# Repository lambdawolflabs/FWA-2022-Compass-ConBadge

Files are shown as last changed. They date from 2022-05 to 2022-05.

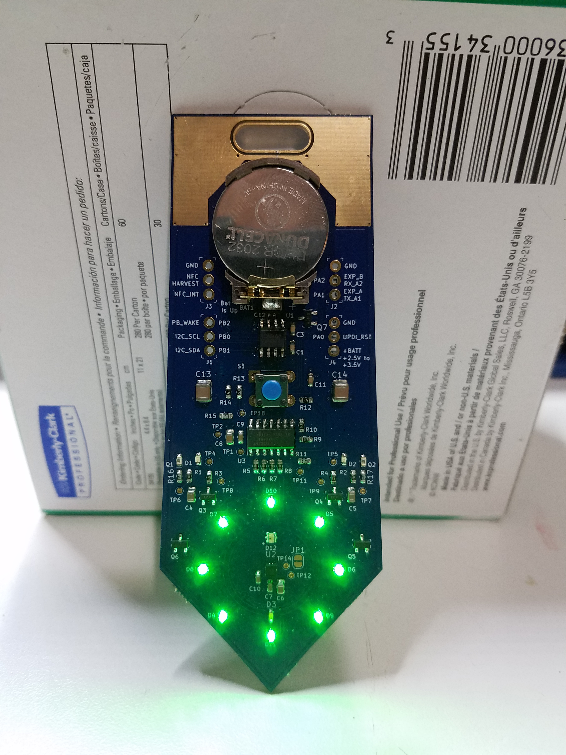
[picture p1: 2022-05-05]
misc/20220504_211331.jpg

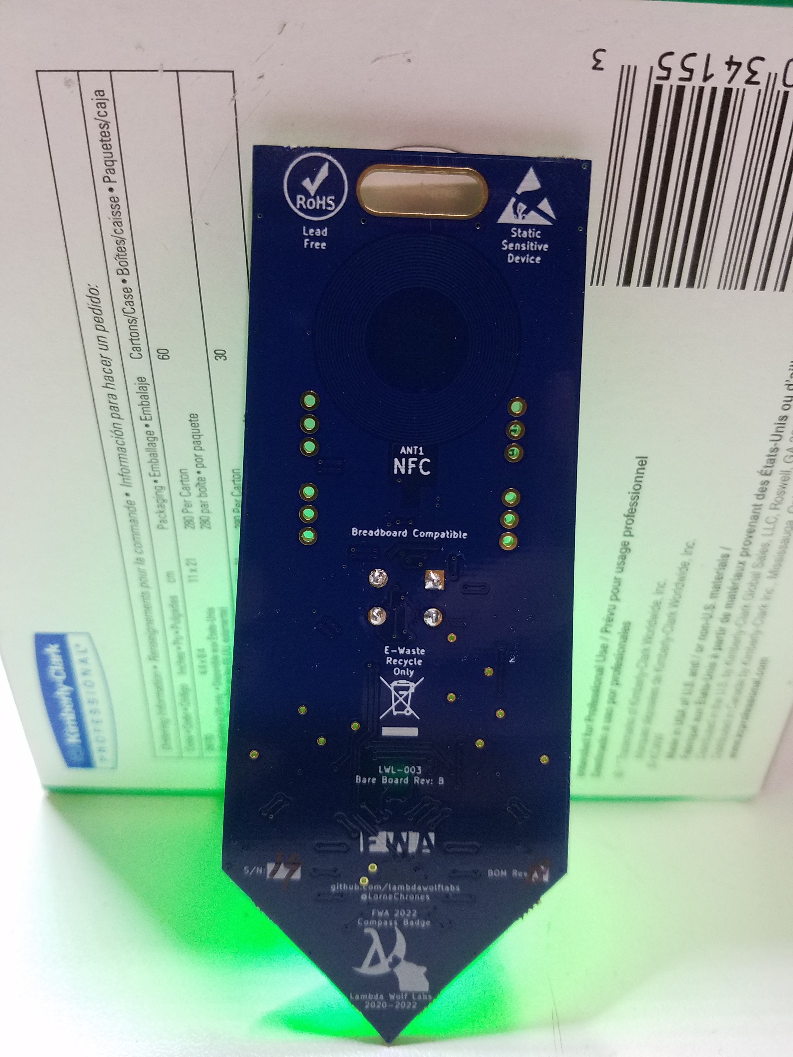
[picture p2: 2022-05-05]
misc/20220504_211339.jpg

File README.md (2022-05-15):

# FWA-2022-Compass-ConBadge
FWA 2022 Compass ConBadge from the Intro To DIY Electronics &amp; Electrical Engineering Panel!

Slides: https://docs.google.com/presentation/d/1c4_kWb6G9Z7fMHBQ-3chpQz8QXO9tOMy/edit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

Recorded Panel: https://www.youtube.com/watch?v=K9LNleyEv4E 

Purpose: Semi-basic, semi-intelligent, semi-interactive conbadge with LED compass function, two BJT transistor multivibrator flasher (can be disabled by MCU), MCU runs the show and built in NFC tag.

Specs:
	
	>Operating/Storage Ambient Temperature Range: 0°C to 40°C.
	
	>Operating/Storage Ambient Humidity Range: 10% to 95% RH.
	
	>Atlantis TLE Theme. Atlantean Crystal Necklace in color (Blue soldermask) and overall shape. 
		
		>PCB is in a truncated cone/prism pill shape with a multi-angled (rounded) arrow end at the large side of the truncation. ~2-3" long by ~1.5" wide.
			
			>Large arrow rounded end is for the compass sensor and compass LEDs.
			
			>Shaft holds most of the electronics (MCU, NFC transiever, pushbutton, etc).
			
			>Smaller flat end holds the battery mount, NFC antenna and lanyard hole.
			
			>NFC antenna is circular with a similar (copyright legal) look to the Eye of Atlantis.

Goals & Requirements:
	
	-EU ROHS3 COMPLIANT
	
	-NO EXPLICIT ESD PROTECTION.
	
	-Has a hole for a keychain or lanyard hook.
	
	-Powers off a single CR2032.
		
		-Lasts atleast 12 hours of continuous compass function (MCU/Compass active + compass LED) and nominal frequency multivibrator flasher (one LED lit at a time): <7mA
		
		-Lasts atleast 24 hours of continuous nominal frequency multivibrator flasher alone (one LEDs lit at any given time)
		
		-Lasts atleast 8 hours of continuous EVERYTHING ON/MAXED OUT operation.
	
	-Simple 2 BJT transistor astable multivibrator circuit.
	
	-Simple integrated NFC rewriteable tag that can be programmed via smartphone.
		
		-Antenna is fully made in PCB FR-4.
		
		-NFC tag harvest output can be used to power downstream circuits without coin cell (optional).
	
	-Compass function:
		
		-Three axis magnetoer/compass sensor (+ accel and/or gyro? optional) for determining which way is north.
		
		-MCU reads this off.
		
		-Charlieplexed LED array in 8 point circle. Only a single LED lights up to point which way is north.
		
		-Reprogrammable MCU (Only wakes up upon button hold to update compass).
	
	-Optional White LED for general illumination.
	
	-Optional RGB LED for customization (Vanilla FW reads the RGB value stored in the NFC chip).
	
	-Additional pins from the MCU broken out for UPDI reprogramming (FTDI pinout), two additional GPIOs (+ VDD & GND).
	
	-OSHPark Prototype PCB Process Compatible

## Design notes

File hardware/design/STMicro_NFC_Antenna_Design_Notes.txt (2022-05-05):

ST25DV04 NFC Antenna Design (See AN2866)

fNFC_min = 13.553MHz
fNFC_typ = 13.56MHz
fNFC_max = 13.567MHz

Operating field according to ISO (across -40 - 85C):
min: 150 mA/m
max: 5000 mA/m

ST25DV04 SOIC-8 Internal Tuning Capacitance:
min = 26.5pF
typ = 28.5pF
max = 30.5pF

Ideal Antenna Inductance (assuming no other parasitics & typ NFC frequency):
min = 5.984uH
typ = 4.833uH
max = 4.516uH

Ideal Antenna Geometry (assuming no other parasitics & 4.833uH Antenna Inductance):
Circular Spiral Geometry:
Turns: 25
Conductor Spacing: 0.18mm
Conductor Width: 0.18mm
Outer Diameter: 19.5mm
	Inner Diameter: 1.86mm
	Fill Factor: 0.8258um
	Resultant Inductance: 4.825uH 
	Calculated Trace Length: 2383mm
	Calculated Trace Resistance (1oz cu, 35um): 6.43 Ohms

Octagonal Spiral Geometry (opt 1):
Turns: 24
Conductor Spacing: 0.18mm
Conductor Width: 0.18mm
Outer Diameter: 19.5mm
	Inner Diameter: 2.58mm
	Fill Factor: 0.7663um
	Resultant Inductance: 4.830uH
	Calculated Trace Length: 1119mm
	Calculated Trace Resistance (1oz cu, 35um): 3.02 Ohms

Octagonal Spiral Geometry (opt 2):
Turns: 15
Conductor Spacing: 0.18mm
Conductor Width: 0.18mm
Outer Diameter: 21.5mm
	Inner Diameter: 11.06mm
	Fill Factor: 0.3206um
	Resultant Inductance: 4.841uH
	Calculated Trace Length: 864mm
	Calculated Trace Resistance (1oz cu, 35um): 2.33 Ohms

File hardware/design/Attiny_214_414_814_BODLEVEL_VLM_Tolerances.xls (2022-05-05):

BODLEVEL (V) | BODLEVEL HYS (V) | BODLEVEL ABS MAX, No Hys (V) | BODLEVEL ABS MIN, No Hys (V) | High Side Tol, No Hys (%) | Low Side Tol, No Hys (%)
4.2 | 0.08 | 4.5 | 3.9 | 6.897 | 7.407
2.6 | 0.04 | 2.9 | 2.4 | 10.909 | 8.000
1.8 | 0.025 | 2 | 1.7 | 10.526 | 5.714
 |  |  |  |  | Voltage Level Monitor (VLM) Setpoints
BODLEVEL (V) | Calc. High Side Tol (%) | Calc. Low Side Tol (%) | Calc. ABS Max + Calc. Hys (V) | Calc. ABS Min + Calc. Hys (V) | 5% Over ABS Max (V) | 5% O. ABS Min (V) | 15% Over Abs Max (V) | 15% O. Abs Min (V) | 25% Over Abs Max (V) | 25% O. Abs Min (V)
1.8 | 10.526 | 5.714 | 2.025 | 1.675 | 2.126 | 1.759 | 2.329 | 1.926 | 2.531 | 2.094
2.15 | 10.890 | 6.926 | 2.415 | 2.032 | 2.536 | 2.134 | 2.778 | 2.337 | 3.019 | 2.540
2.6 | 10.909 | 8.000 | 2.940 | 2.360 | 3.087 | 2.478 | 3.381 | 2.714 | 3.675 | 2.950
2.95 | 10.576 | 8.459 | 3.310 | 2.748 | 3.475 | 2.885 | 3.806 | 3.160 | 4.137 | 3.435
3.3 | 9.938 | 8.588 | 3.684 | 3.072 | 3.868 | 3.226 | 4.236 | 3.533 | 4.605 | 3.840
3.7 | 8.835 | 8.332 | 4.093 | 3.458 | 4.298 | 3.631 | 4.707 | 3.976 | 5.116 | 4.322
4 | 7.747 | 7.858 | 4.384 | 3.760 | 4.603 | 3.948 | 5.042 | 4.324 | 5.480 | 4.700
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

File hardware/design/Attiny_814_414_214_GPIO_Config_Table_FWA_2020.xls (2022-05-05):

Physical Pin # | Pin Function/Software Pin # | Netname | Peripheral | Direction | Notes
10 | PA0 | UPDI_RST | UPDI / RESET | In | Dedicated programming/reset/debug pin.
11 | PA1 | EXP_A_TXD_A1 | GPIO | In | Expansion GPIO pin (Either ADC AIN1, BREAK, UART TXD or other misc. functions) - Brought out to board edge.
12 | PA2 | EXP_B_RXD_A2 | GPIO | In | Expansion GPIO pin (Either ADC AIN2, EVOUT0, UART RXD or other misc. funcs) - Brought out to board edge.
13 | PA3 | INT_MUX | GPIO/ADC | In | Multiplexed interrupt line from NFC tag & Magnetometer (ADC decoding, digital falling/rising edge detection to check for both Hi-Z or one/both pulled low)
2 | PA4 | LED_CHARLIE_A | GPIO | Out | Charlieplexed output for LED array (A)
3 | PA5 | LED_CHARLIE_B | GPIO | Out | Charlieplexed output for LED array (B)
4 | PA6 | LED_CHARLIE_C | GPIO | Out | Charlieplexed output for LED array (C)
5 | PA7 | LED_CHARLIE_D | GPIO | Out | Charlieplexed output for LED array (D)
9 | PB0 | I2C_SCL | I2C (SCL) | Out | Board I2C Bus - Brought out to board edge.
8 | PB1 | I2C_SDA | I2C (SDA) | Bidirectional | Board I2C Bus - Brought out to board edge.
7 | PB2 | PB_WAKE | GPIO | In | Wakeup Pushbutton/multifunction pushbutton - Brought out to board edge.
6 | PB3 | BLINK_DIS | GPIO | Out | GPIO disable/enable for the two transistor multivibrator oscillator.
 | See the Attiny814 datasheet for the latest revision to the pinout.

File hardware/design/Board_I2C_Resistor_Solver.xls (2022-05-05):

Device Name | Device RefDes | Device I2C/TWI Pin Capacitance (pF)
Attiny414 | U3 | 10
LIS3MDLTR | U2 | 8
ST25DV04K | U1 | 10
I2C Expansion Device From J1 | - | 8
I2C Net Trace Capacitance (0.18mm width, FR4, 1.52mm core thickness, 6.5cm total length), pF: |  |  | 3
I2C Expanson Bus J1 Wire Capacitance (Arbitrary 22AWG hook-up wire + 2pF Breadboard capacitance), pF: |  |  | 2.5
I2C Target Speed (kHz): | 100
I2C Rise Time (uS): | 1
Maximum I2C Pull Up Resistor (kΩ): | 28.4390246

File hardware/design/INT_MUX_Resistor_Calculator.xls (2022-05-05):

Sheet: Only MAG_INT and NFC_INT
MCU or Ext Pullup Typ: | 27 | kΩ
MCU or Ext Pullup Tol: | 1.2 | %
ST25DV04 GPO Open Drain Max: | 0.4 | kΩ |  | Note: Open Drain Drive can vary from 50Ω to typ 200Ω to max 400Ω
LIS3MDL INT Output Impedance Max: | 0.06 | kΩ
NFC_INT PD Res Typ: | 4.7 | kΩ | Parallel Combo: | 2.889344262 | kΩ
NFC_INT PD Res Tol: | 1.2 | % | Total Error: | 3.6851 | %
 |  |  |  |  |  |  | 0.0034155
MAG_INT PD Res Typ: | 7.5 | kΩ
MAG_INT PD Res Tol: | 1.2 | % | MCU ADC Bits: | 10 | Bits
LIS3MDL & ST25DV04 Max Pin Leakage: | 0.2 | uA
 | 3.2 | Vin |  |  |  | 3 | Vin |  |  |  | 2.5 | Vin
Combination | Vmeasure Typ | Vmeasure Max | Vmeasure Min | VIH Min | VIL Max | Vmeasure Typ | Vmeasure Max | Vmeasure Min | VIH Min | VIL Max | Vmeasure Typ | Vmeasure Max | Vmeasure Min | VIH Min | VIL Max
Both Hi-z | 3.200 | 3.200 | 3.189 | 2.240 | 0.960 | 3.000 | 3.000 | 2.989 | 2.100 | 0.900 | 2.500 | 2.500 | 2.489 | 1.750 | 0.750
NFC_INT shorted, MAG_INT Hi-Z | 0.469 | 0.486 | 0.452 | 2.240 | 0.960 | 0.439 | 0.456 | 0.423 | 2.100 | 0.900 | 0.365 | 0.379 | 0.352 | 1.750 | 0.750
NFC_INT Hi-Z, MAG_INT shorted | 0.690 | 0.716 | 0.665 | 2.240 | 0.960 | 0.647 | 0.671 | 0.623 | 2.100 | 0.900 | 0.538 | 0.558 | 0.518 | 1.750 | 0.750
Both shorted | 0.309 | 0.321 | 0.298 | 2.240 | 0.960 | 0.290 | 0.301 | 0.279 | 2.100 | 0.900 | 0.242 | 0.251 | 0.233 | 1.750 | 0.750
Min Delta Between States: | 0.1597102284 |  |  |  |  | 0.1493908391 |  |  |  |  | 0.123592366
Max Percentage Spread: | 0.1180327003 |  |  |  |  | 0.1106624875 |  |  |  |  | 0.09223695557
Max ADC Resolution: | 0.003125 |  |  |  |  | 0.0029296875 |  |  |  |  | 0.00244140625
Max (Delta BW States - Percentage Spread) in ADC Steps: | 13 |  |  |  |  | 13 |  |  |  |  | 12
Values & Tolerances Good? (Also accounts for all ADC drift, error & linearity): | YES |  |  |  |  | YES |  |  |  |  | YES
Max of any shorted condition (V): | 0.716 |  |  |  |  | 0.671 |  |  |  |  | 0.558
Less than max VIL? | YES |  |  |  |  | YES |  |  |  |  | YES
Confirmed MAG_INT is indeed a open-drain ouput according to the ST Micro forums

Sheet: CMOS MAG_INT Alternate
MCU or Ext Pullup Typ: | 27 | kΩ
MCU or Ext Pullup Tol: | 1.2 | %
ST25DV04 GPO Open Drain Max: | 0.4 | kΩ
LIS3MDL INT Output Impedance Max: | 0.06 | kΩ
NFC_INT PD Res Typ: | 4.7 | kΩ
NFC_INT PD Res Tol: | 1.2 | %
MAG_INT Res Typ: | 7.5 | kΩ
MAG_INT Res Tol: | 1.2 | %
LIS3MDL & ST25DV04 Max Pin Leakage: | 0.2 | uA
MCU / EXT Pullup || MAG_INT Resistor: | 5.869565217
MAG_INT HIGH, NFC_INT shorted low v-divider factor (Typ): | 0.445

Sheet: MAG_INT + MAG_DRDY or NFC_INT
Device: | LIS3MDL |  | ST25DV04K-IER
Combination | MAG_INT (7.5kΩ) | MAG_DRDY (through MAG_INT Resist) | NFC_INT (4.7kΩ) | Captured? | Sim Timecode? (sec) | Verified? | Board Verified? | INT_MUX Nominal (V) | ADC LSB @ 3V # | INT_MUX + Variance (V) | INT_MUX - Variance (V) | Max Variance From Nominal (V) | Max Var/2 | Above VIH or Below VIL? | Device Detected | Combination Overlap Detected? | Variance to ADC LSBs*
1 | Hi-Z | Hi-Z | Hi-Z | Yes | 0 to 0.2 | YES | YES | 2.98 | 1016 | 3 | 2.95 | 0.03 | 0.015 | Yes | None | No | 9
5 | LOW | Hi-Z | Hi-Z | Yes | 0.77 to 0.98 | YES | YES | 0.67 | 228 | 0.691 | 0.645 | 0.025 | 0.0125 | Yes | LIS3MDL | No | 7
2 | Hi-Z | Hi-Z | LOW | Yes | 1.55 to 1.7 | YES | YES | 0.465 | 158 | 0.486 | 0.442 | 0.023 | 0.0115 | Yes | ST25DV04K | No | 6
6 | LOW | Hi-Z | LOW | Yes | 1.05 to 1.45 | YES | YES | 0.301 | 102 | 0.315 | 0.287 | 0.014 | 0.007 | Yes | LIS3MDL & ST25DV04K | No | 4
3 | Hi-Z | LOW | Hi-Z | Yes | 0.26 to 0.48 | YES | YES | 0.667 | 227 | 0.691 | 0.645 | 0.024 | 0.012 | Yes | LIS3MDL | No | 7
7 | LOW | LOW | Hi-Z | Yes | 0.51 to 0.73 | YES | YES | 0.661 | 225 | 0.678 | 0.643 | 0.018 | 0.009 | Yes | LIS3MDL | No | 5
4 | Hi-Z | LOW | LOW | Yes | 1.76 to 1.98 | YES | YES | 0.301 | 102 | 0.315 | 0.287 | 0.014 | 0.007 | Yes | LIS3MDL & ST25DV04K | No | 4
8 | LOW | LOW | LOW | Yes | 3.27 to 3.4 | YES | YES | 0.3 | 102 | 0.312 | 0.287 | 0.013 | 0.0065 | Yes | LIS3MDL & ST25DV04K | No | 3
 |  |  |  |  |  |  |  |  |  |  | Note: This is assuming MAG_INT and MAG_DRDY ARE tied together through the same resistor to INT_MUX
 |  |  |  |  |  |  |  |  |  |  | Note: Variance assumes W.C across 50Ω,200Ω,400Ω open drain resistance, 1% tolerant resistors and 0.2% temp variation
 |  |  |  |  |  |  |  |  |  |  | Note: *ATTINY814 ADC LSB with VCC as the VREF, 10-bit resolution. W.C. with 3.4V vin.
 |  |  |  |  |  |  |  |  |  |  | Device Detected | ADC LSB Nominal Average* | ADC LSB W.C. Upper Range* | ADC LSB W.C. Lower Range*
 |  |  |  |  |  |  |  |  |  |  | None | 1016 | 1023 | 1005
 |  |  |  |  |  |  |  |  |  |  | LIS3MDL | 226 | 235 | 219
 |  |  |  |  |  |  |  |  |  |  | ST25DV04K | 158 | 165 | 150
 |  |  |  |  |  |  |  |  |  |  | LIS3MDL & ST25DV04K | 102 | 107 | 97

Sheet: MAG_INT, NFC_INT and MAG_DRDY
Combination | MAG_INT (7.5kΩ) | MAG_DRDY (1kΩ) | NFC_INT (4.7kΩ) | Captured? | Sim Timecode? (sec) | Verified? | INT_MUX Nominal (V) | ADC LSB @ 3V # | INT_MUX + Variance (V) | INT_MUX - Variance (V) | Max Variance From Nominal (V) | Max Var/2 | Above VIH or Below VIL? | Combination Overlap Detected? | Combination Buffer (V) | Buffer # Of ADC LSBs *
1 | Hi-Z | Hi-Z | Hi-Z | Yes | 0 to 0.2 | YES | 2.98 | 1016 | 3 | 2.9 | 0.08 | 0.04 | Yes | No | 2.208 | 664
5 | LOW | Hi-Z | Hi-Z | Yes | 0.77 to 0.98 | YES | 0.682 | 232 | 0.692 | 0.669 | 0.013 | 0.0065 | Yes | No | 0.182 | 54
2 | Hi-Z | Hi-Z | LOW | Yes | 1.55 to 1.7 | YES | 0.482 | 164 | 0.487 | 0.469 | 0.013 | 0.0065 | Yes | No | 0.153 | 46
6 | LOW | Hi-Z | LOW | Yes | 1.05 to 1.45 | YES | 0.311 | 106 | 0.316 | 0.304 | 0.007 | 0.0035 | Yes | No | 0.153 | 46
3 | Hi-Z | LOW | Hi-Z | Yes | 0.26 to 0.48 | YES | 0.15 | 51 | 0.151 | 0.146 | 0.004 | 0.002 | Yes | No | 0.017 | 5
7 | LOW | LOW | Hi-Z | Yes | 0.51 to 0.73 | YES | 0.128 | 43 | 0.129 | 0.124 | 0.004 | 0.002 | Yes | POTENTIAL COLLISION DETECTED | 0.004 | 1
4 | Hi-Z | LOW | LOW | Yes | 1.76 to 1.98 | YES | 0.119 | 40 | 0.12 | 0.115 | 0.004 | 0.002 | Yes | POTENTIAL COLLISION DETECTED | 0.009 | 2
8 | LOW | LOW | LOW | Yes | 3.27 to 3.4 | YES | 0.104 | 35 | 0.106 | 0.101 | 0.003 | 0.0015 | Yes | No | 0.101 | 30
 |  |  |  |  |  |  |  |  |  | Note: This is assuming MAG_INT and MAG_DRDY are NOT tied together through the same resistor to INT_MUX.
 |  |  |  |  |  |  |  |  |  | Note: Variance assumes W.C. open drain resistance, 1% tolerant resistors and 0.2% temp variation
 |  |  |  |  |  |  |  |  |  | Note: ATTINY814 ADC LSB with VCC as the VREF, 10-bit resolution. W.C. with 3.4V vin.

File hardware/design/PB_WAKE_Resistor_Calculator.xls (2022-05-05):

MCU or Ext Pullup Typ: | 35 | kΩ
MCU or Ext Pullup Tol: | 43 | %
Pushbutton PD Resistor Typ (Ideal Pushbutton): | 4.7 | kΩ
Pushbutton PD Resistor Tol (Ideal Pushbutton): | 1.2 | %
PB_WAKE Capacitor Typ: | 100 | nF
PB_WAKE Capacitor Tol: | 20 | %
MCU VIL Max (Factor): | 0.3 | Factor
MCU VIH Min (Factor): | 0.7 | Factor
MCU W/C GPIO Leakage Current: | 0.050 | uA
Pushbutton Pressed, W/C VIL Factor on PB_WAKE: | 0.193 | Factor
Pressed Condition Less Than MCU VIL Max? | YES
Pushbutton Released, W/C VIH Factor on PB_WAKE: | 0.9974975 | Factor
Released Condition Greater Than MCU VIH Min? | YES
Pushbutton Falling RC Time Typ: | 0.00047 | Sec
Pushbutton Falling RC Time Tol (Calculated): | 21.2 | %
Pushbutton Rising RC Time Typ: | 0.0035 | Sec
Pushbutton Rising RC Time Tol (Calculated): | 63.000 | %

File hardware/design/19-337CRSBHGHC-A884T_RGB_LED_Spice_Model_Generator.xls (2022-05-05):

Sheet: Red
Everlight 19-337C/RSBHGHC-A88/4T RGB LED SMT | RED
From datasheet |  | 69.97 | IS: | 1.6137e-10
 |  | 0.53 | N: | 2.979
Datasheet 25°C Ambient
 |  | .model 19-337_RED D(Is=1.6137e-10 N=2.979)
 |  |  | IS: | 1.6137e-10
 |  |  | N: | 2.979
 |  |  | Rs:
Datasheet VD (V) | Datasheet IF (mA) | Calculated IF (mA) |  | % Diff
1.781 | 0.9 | 1.868661637 |  | -69.9732769
1.8 | 2.3 | 2.392720416 |  | -3.95167015
1.829 | 5 | 3.489467683 |  | 35.58603139
1.859 | 7.7 | 5.155573703 |  | 39.58479576
1.885 | 10 | 7.23090146 |  | 32.14107568
1.918 | 13.1 | 11.10866946 |  | 16.45138363
1.94 | 15 | 14.79023627 |  | 1.408271661
2 | 20 | 32.2857404 |  | -46.99461194
 |  |  |  |  | Max Percent Diff: | 69.9732769
 |  |  |  |  | Avg Percent Diff: | 0.5314998924
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

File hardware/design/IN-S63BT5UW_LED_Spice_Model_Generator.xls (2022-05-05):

Inolux IN-S63BT5UW 0603 White LED
From datasheet |  | .MODEL IN-S63BT5UW D(Is=3.8462e-11 N=4.5828)
 |  | 46.206 | IS: | 3.8462e-11
Datasheet 25°C Ambient |  | 0.148 | N: | 4.583
 |  |  | IS: | 3.8462e-11
 |  |  | N: | 4.5828
Datasheet VD (V) | Datasheet IF (mA) | Calculated IF (mA) |  | % Diff
2.64 | 0.142 | 0.1914419228 |  | -29.65549284
2.75 | 0.428 | 0.4853767062 |  | -12.56364561
2.892 | 2.21 | 1.613096206 |  | 31.22619793
3 | 6.07 | 4.02120243 |  | 40.60561829
3.085 | 10 | 8.252207096 |  | 19.15157871
3.1582 | 15 | 15.32645187 |  | -2.152918338
3.25 | 20.785 | 33.3144726 |  | -46.32012846
 |  |  |  |  | Max Percent Diff: | 46.32012846
 |  |  |  |  | Avg Percent Diff: | 0.04160138304

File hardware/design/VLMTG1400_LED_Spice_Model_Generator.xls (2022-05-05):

Vishay VLMTG1400 Green 0603 LED
From datasheet (https://www.vishay.com/docs/84393/vlmtg1400.pdf) |  | .MODEL VLMTG1400 D (Is=1.3882e-6 N=6.469)
Datasheet 25°C Ambient
 |  |  | IS: | 1.3882e-06
 |  |  | N: | 6.469
Datasheet VD (V) | Datasheet IF (mA) | Calculated IF (mA) |  | % Diff
2.308 | 1 | 1.406521636 |  | -33.78499742
2.374 | 2 | 2.088750323 |  | -4.341195521
2.421 | 3 | 2.768128702 |  | 8.03974078
2.465 | 4 | 3.603127615 |  | 10.4397139
2.5 | 5 | 4.443793852 |  | 11.77929456
2.528 | 6 | 5.255491126 |  | 13.22925611
2.559 | 7 | 6.328183607 |  | 10.08113953
2.588 | 8 | 7.529057082 |  | 6.065312478
2.61 | 9 | 8.589883173 |  | 4.663098928
2.632 | 10 | 9.80017709 |  | 2.018395179
2.798 | 20 | 26.49634775 |  | -27.94347541
 |  |  |  |  | Max Percent Diff: | 33.78499742
 |  |  |  |  | Avg Percent Diff | 0.02238937399

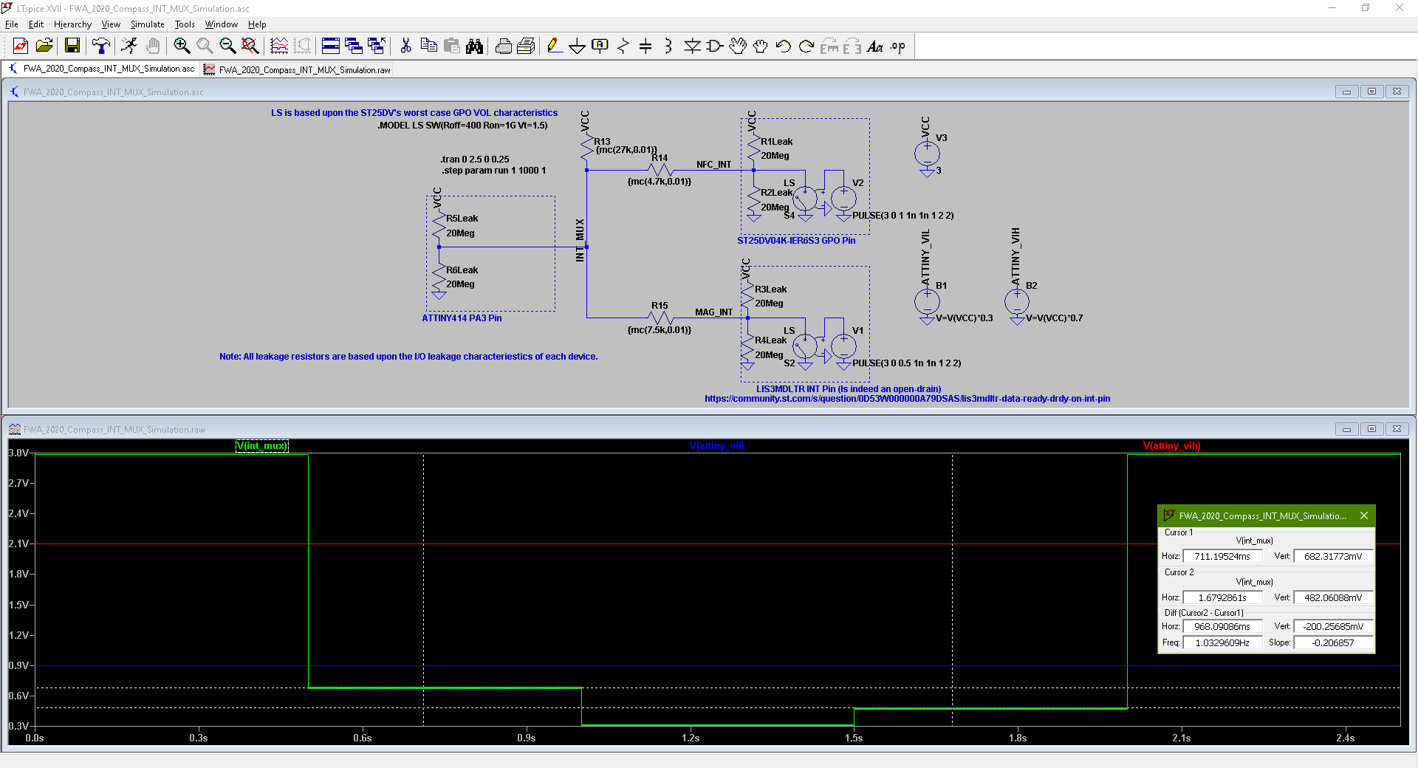
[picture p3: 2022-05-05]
hardware/design/sims/FWA_2020-2022_Compass_INT_MUX_Simulation.PNG

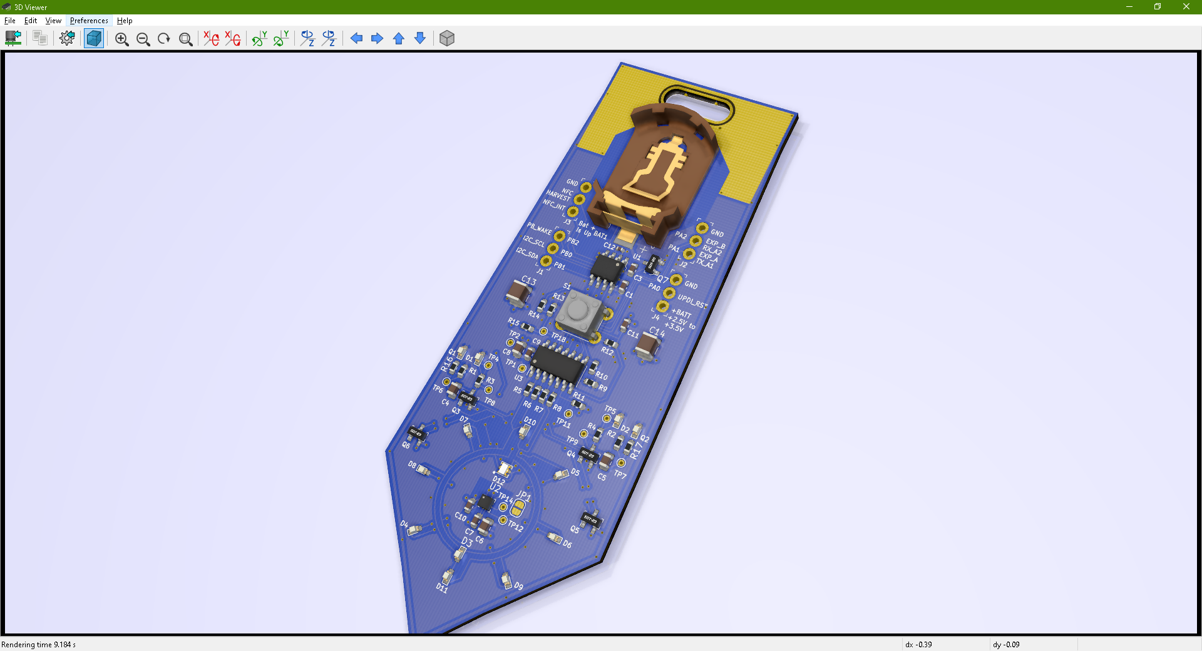
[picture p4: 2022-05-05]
misc/vB_PCBA_3D_Render_Front.png

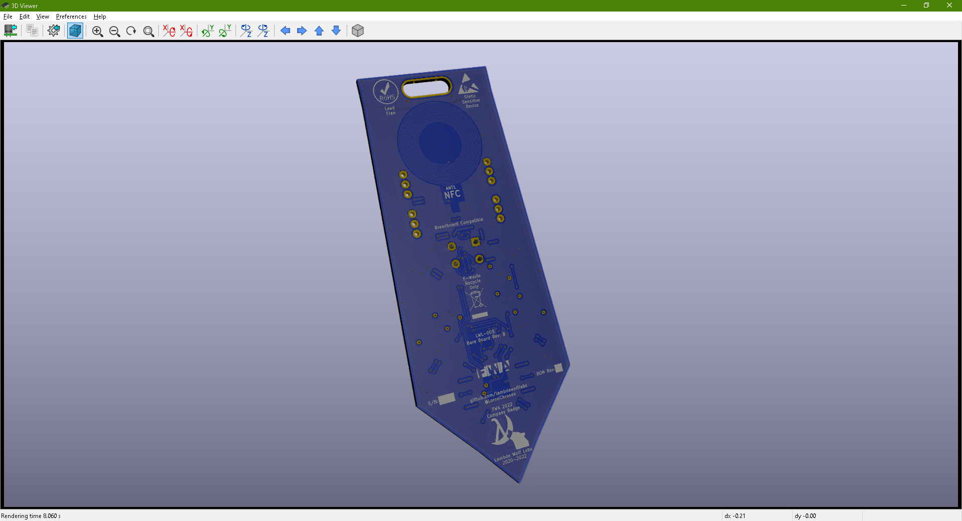
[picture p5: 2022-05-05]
misc/vB_PCBA_3D_Render_Back.png

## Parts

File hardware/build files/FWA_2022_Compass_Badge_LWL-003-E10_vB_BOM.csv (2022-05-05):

BOM/Design Name: | FWA 2022 Compass Badge
Drawing Number: | LWL-003-E13
Revision: | B
Company: | Lambda Wolf Labs (@LorneChrones)
Date: | 2/13/2022 18:50
Tool: | Eeschema (5.1.2)-2
Populated Component Count: | 53
Number of DNP Components: | 7
Line Item | Reference Designator | Qty | Value | Footprint | MPN | Manufacturer | Description | Vendor | Type | Notes
1 | BAT1 | 1 | S8421-45R | LWL-library:BattteryHolder_Harwin_S8421R | S8421-45R | Harwin Inc. | BATTERY HOLDER COIN 20MM SMD |  | SMD
2 | C1, C3, C7, C10, C9, C11 | 6 | CL10B104KB8NNNL | Capacitor_SMD:C_0603_1608Metric | CL10B104KB8NNNL | Samsung Electro-Mechanics | CAP CER 0.1UF 50V X7R 0603 |  | SMD
3 | C4, C5 | 2 | CL21A226MQQNNNE | Capacitor_SMD:C_0805_2012Metric | CL21A226MQQNNNE | Samsung Electro-Mechanics | CAP CER 22UF 6.3V X5R 0805 |  | SMD
4 | C8, C6 | 2 | CL21A106MQFNNNE | Capacitor_SMD:C_0805_2012Metric | CL21A106MQFNNNE | Samsung Electro-Mechanics | CAP CER 10UF 6.3V X5R 0805 |  | SMD
5 | C13, C14 | 2 | CL32A107MPVNNNE | Capacitor_SMD:C_1210_3225Metric | CL32A107MPVNNNE | Samsung Electro-Mechanics | CAP CER 100UF 10V X5R 1210 |  | SMD
6 | D3 | 1 | IN-S63BT5UW | digikey-footprints:LED_0603 | IN-S63BT5UW | Inolux | LED WHITE CLEAR 0603 SMD |  | SMD
7 | D11, D10, D8, D9, D4, D5, D1, D2, D6, D7 | 10 | VLMTG1400-GS08 | digikey-footprints:LED_0603 | VLMTG1400-GS08 | Vishay Semiconductor Opto Division | LED GREEN 0603 SMD |  | SMD
8 | D12 | 1 | 19-337C_RSBHGHC-A88_4T | LWL-library:6-0606_1.6x1.6mm_19-337C_Everlight | 19-337C/RSBHGHC-A88/4T | Everlight Electronics Co Ltd | TRI COLOR PCB TOP VIEW SMD LED R |  | SMD
9 | Q1, Q2 | 2 | PT19-21C_L41_TR8 | LWL-library:PHOTOTRAN_0603 | PT19-21C/L41/TR8 | Everlight Electronics Co Ltd | SENSOR PHOTO 940NM TOP VIEW 0603 |  | SMD
10 | Q4, Q3 | 2 | MMBT2222ALT1G | digikey-footprints:SOT-23-3 | MMBT2222ALT1G | ON Semiconductor | TRANS NPN 40V 0.6A SOT23 |  | SMD
11 | Q6, Q5 | 2 | BSS138-7-F | digikey-footprints:SOT-23-3 | BSS138-7-F | Diodes Incorporated | MOSFET N-CH 50V 200MA SOT23-3 |  | SMD
12 | Q7 | 1 | NXV75UPR | digikey-footprints:SOT-23-3 | NXV75UPR | Nexperia USA Inc. | P-Channel 20 V 1.8A (Ta) 340mW (Ta), 2.1W (Tc) Surface Mount TO-236AB |  | SMD
13 | R2, R1 | 2 | RK73H1JTTD2004F | Resistor_SMD:R_0603_1608Metric | RK73H1JTTD2004F | KOA Speer Electronics, Inc. | RES 2M OHM 1% 1/10W 0603 |  | SMD
14 | R3, R4, R5, R6, R7, R8 | 6 | CR0603-FX-82R0ELF | Resistor_SMD:R_0603_1608Metric | CR0603-FX-82R0ELF | Bourns | RES SMD 82 OHM 1% 1/10W 0603 |  | SMD
15 | R9, R10, R13 | 3 | CRGCQ0603F27K | Resistor_SMD:R_0603_1608Metric | CRGCQ0603F27K | TE Connectivity Passive Product | CRGCQ 0603 27K 1% |  | SMD
16 | R11 | 1 | RMCF0603FT100K | Resistor_SMD:R_0603_1608Metric | RMCF0603FT100K | Stackpole | RES 100K OHM 1% 1/10W 0603 |  | SMD
17 | R12, R14 | 2 | RC0603FR-074K7L | Resistor_SMD:R_0603_1608Metric | RC0603FR-074K7L | Yageo | RES SMD 4.7K OHM 1% 1/10W 0603 |  | SMD
18 | R15, R16, R17 | 3 | RMCF0603FT7K50 | Resistor_SMD:R_0603_1608Metric | RMCF0603FT7K50 | Stackpole Electronics Inc | RES 7.5K OHM 1% 1/10W 0603 |  | SMD
19 | S1 | 1 | PTS645SM43-2_LFS | LWL-library:Switch_Tactile_THT_6x6mm_PTS645S | PTS645SM43-2 LFS | C&K | SWITCH TACTILE SPST-NO 0.05A 12V |  | TH
20 | U1 | 1 | ST25DV04K-IER6S3 | digikey-footprints:SOIC-8_W3.9mm | ST25DV04K-IER6S3 | STMicroelectronics | IC RFID TRANSP 13.56MHZ 8SO |  | SMD
21 | U2 | 1 | LIS3MDLTR | digikey-footprints:VFLGA-12_2x2mm_6milFriendly | LIS3MDLTR | STMicroelectronics | SENSOR MR I2C/SPI 12LGA |  | SMD
22 | U3 | 1 | ATtiny814-SSNR | Package_SO:SOIC-14_3.9x8.7mm_P1.27mm | ATtiny814-SSNR | Microchip Technology | 20MHz, 8kB Flash, 512B SRAM, 128B EEPROM, SOIC-14 |  | SMD

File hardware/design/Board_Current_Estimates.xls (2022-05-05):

Device P/N | RefDes | Op Temp Range (°C) | Min Op Voltage (V) | Max Op Voltage (V) | Typ Sleep Current (uA) | Sleep Current Conditions/Notes | Typ/Avg Normal Mode Current (uA) | Normal Mode Current Conditions/Notes | Typ/Avg High Power Mode (uA) | High Power Mode Current Conditions/Notes | W.C. Surge/Peak Current (uA) | W.C. Surge/Peak Current Duration (mS) | W.C. Surge/Peak Current Conditions/Notes
LIS3MDLTR | U2 | -40 to +85 | 1.9 | 3.6 | 1 | Powered down, Vdd=2.5V, +25C | 40 | Low-power mode, ODR=20Hz, Vdd=2.5V, +25C | 270 | Ultra-high-resolution mode, ODR=20Hz, Vdd=2.5V, +25C | N/A |  | N/A
ST25DV04K-IER6S3 | U1 | -40 to +85 | 1.8 | 5.5 | 1.3 | Low powered down (LPD=1), Vcc=3.3V, +25C | 76 | On power up, idle, Vcc=3.3V, +25C | 280 | Write, MB address, Vcc=3.3V, fc=1MHz, 50nS rise/fall, +25C | N/A |  | N/A
Two-BJT LED Multivibrator | (Multiple) | -40 to +80 | 1.5 | 3.4 | 60 | MOSFETs Q5/Q6 closed, dark, Vcc=3V, +25C | 7446 | MOSFETs Q5/Q6 open, dark, Vcc=3V, +25C | 10820 | MOSFETs Q5/Q6 open, max brightness, Vcc=3V, +25C | 13600 | 25 | MOSFETs Q5/Q6 open, max brightness, either cap charges, Vcc=3V, +25C
ATtiny814-SS | U3 | -40 to +105 | 1.8 | 5.5 | 0.71 | RTC @ 1kHz from int OSCULP32K, other periphs off VDD=3V +25C Standby | 200 | Idle @ 2MHz, All periphs off Vdd=3V at T=25°C | 500 | Active @ 2MHz, all periphs off, Vdd=3V, +25C | N/A |  | N/A
27kΩ I2C Pullups | R9 & R10 | -40 to +85 | 1.9 | 3.6 | 0.26 | No I2C Activity/Hi-Z both lines, leakage currents, Vcc=3V, +25C | 110 | I2C Activity, 100kHz, 50% Duty Cycle, Vcc=3V, +25C | 110 | I2C Activity, 100kHz, 50% Duty Cycle, Vcc=3V, +25C | 225 | 0.005 | I2C Activity, 100kHz, 50% Duty Cycle, Vcc=3V, +25C
100KΩ Q5/Q6 G Pulldown | R11 | -40 to +85 | 1.8 | 5.5 | 0.15 | Hi-Z, MOSFET gates passively pulled down, leakage currents, Vcc=3V, +25C | 30 | MOSFET gates Q5/Q6 driven high, Vcc=3V, +25C | 30 | MOSFET gates Q5/Q6 driven high, Vcc=3V, +25C | N/A | N/A | N/A
Pushbutton Circuit | S1, R12, U3 | -40 to +85 | 1.8 | 5.5 | 0.05 | Pushbutton released, internal pull-up enaged, leakage currents, Vcc=3V, +25C | 76 | Pushbutton pressed, int pull-up typ enabled, Vcc=3V, +25C | 76 | Pushbutton pressed, int pull-up typ enabled, Vcc=3V, +25C | N/A | N/A | N/A
INT Mux Circuit | R13-R15 | -40 to +85 | 1.9 | 3.6 | 0.26 | Hi-Z both lines, leakage currents, Vcc=3V, +25C | 105 | Both INT pins pulled low, Vcc=3V, +25C | 105 | Both INT pins pulled low, Vcc=3V, +25C | N/A | N/A | N/A
Charlieplex LED Array | (Multiple) | -30 to +85 | 1.8 | 3.4 | 0.2 | Charlieplex completely off, ATTINY414 IO leakage, Vcc=3V, +25C | 6268 | One of the VLMTG1400 Green LEDs lit, VCC=3V, +25C, 82Ω Resistors | 6757 | 19-337 Blue LED Lit, Vcc=3V, +25C, 82Ω Resistors | N/A | N/A | N/A
 |  | Voltage Op Limits (V) | 1.9 | 3.4
 |  |  |  | Sum Sleep Current (uA) | 63.93
 |  |  |  | Battery Droop on Sleep Current (V) | 2.998642553
 |  |  |  | Estimated Battery Life (Hours) | 3128.42
 |  |  |  |  |  | Sum Normal Mode Current (uA) | 14351
 |  |  |  |  |  | Loaded Battery Droop Voltage From Nominal Battery Voltage Under Normal Current (V) | 2.695280433
 |  |  |  |  |  | Estimated Battery Life, Normal Mode Current Sum (Hours) | 13.94
 |  |  |  |  |  |  |  | Sum High Power Current (uA) | 18948
 |  |  |  |  |  |  |  | Loaded Battery Droop Voltage From Nominal Battery Voltage Under High Current (V) | 2.5976708
 |  |  | CR2032 Datasheets | Nominal ESR @ Midlife & +25C (Ohms) |  |  |  | Estimated Battery Life, High Mode Current Sum (Hours) | 10.56
 |  |  | Energizer CR2032 DS (http://www.cr2032.co/cms/prodimages/energizer_cr2032_datasheet.pdf) | 20
 |  |  | Panasonic CR2302 DS (https://industrial.panasonic.com/cdbs/www-data/pdf2/AAA4000/AAA4000C321.pdf) | NO DATA |  |  |  |  |  | Worst Case Current Peak / Duration (uA / mS) | 13600 | 25
 |  |  | Sanyo CR2032 DS (https://www.farnell.com/datasheets/2949136.pdf) | 20 |  |  |  |  |  | Loaded Battery Droop Voltage From Nominal Battery Voltage Under Peak Current No Capacitance (V) | 2.711226667
Battery Specs (Nominal CR2032) |  |  | Duracell DL2032 DS (https://www.duracell.com/wp-content/uploads/2016/04/LI2032US10141.pdf) | NO DATA |  |  |  |  |  | Surge Charge Consumed ( C ) | 0.00034
Battery Nominal Voltage (V) | 3 |  | Toshiba CR2032 DS (https://www.microbattery.com/pub/media/tech-specs/pdfs/ttsp3/Toshiba_Tech_Data_CR2032.pdf) | NO DATA |  | Multivibrator Only + Idle CPU Current, everything else asleep (uA) | 7649.22 |  |  | Min Capacitance To Meet The Battery Droop (uF) | 125.404491
Battery Nominal ESR (Ω) | 21.23333333 |  | Maxell CR2032 DS (https://biz.maxell.com/en/primary_batteries/CR2032H_DataSheet_16e.pdf) | 23.7 |  | Loaded Battery Droop Voltage From Nominal Battery Voltage Under Normal Current (V) | 2.837581562
Battery EOL Voltage (V) | 2.15 |  |  |  |  | Estimated Battery Life, Multivibrator Only Mode Current Sum (Hours) | 26.15
Battery Nominal Capacity to EOL Voltage (mAh) | 200
 |  |  |  |  |  | Compass Mode Current (Active CPU, Multivib off, Green Compass LED, Compass), sleep (uA) | 7189
 |  |  |  |  |  | Loaded Battery Droop Voltage From Nominal Battery Voltage Under Normal Current (V) | 2.847353567
 |  |  |  |  |  | Estimated Battery Life, Multivibrator Only Mode Current Sum (Hours) | 27.82

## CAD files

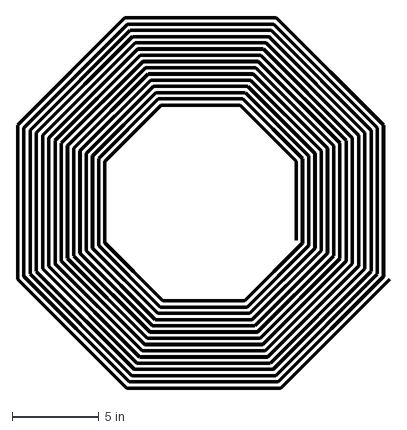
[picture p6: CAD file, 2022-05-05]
hardware/design/Octagon_Spiral_NFC_Antenna_mm.dxf
21.7 x 21.6 in

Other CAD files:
hardware/design/Octagon_Spiral_NFC_Antenna_mm.dwg

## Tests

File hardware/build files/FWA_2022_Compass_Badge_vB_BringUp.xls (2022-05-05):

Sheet: Measurement List
FWA 2022 Compass Badge Bring Up (vB PCBAs)
2022-04-01
(Done by @LorneChrones)
Order | Test/Measurement | SN001 | SN002 | SN003 | SN004 | SN005 | SN006 | SN007 | SN008 | SN009 | SN010 | SN011 | SN012 | SN013 | SN014 | SN015 | SN016 | SN017 | SN018 | SN019 | SN020
1 | Visual Inspection | PASS | PASS | PASS | PASS | PASS | PASS | PASS | PASS | PASS | PASS | PASS | PASS | PASS | PASS | PASS | PASS | PASS | PASS | PASS | PASS | 2022-04-10
2 | Open-Shorts | PASS | PASS | PASS | PASS | PASS | PASS | PASS | PASS | PASS | PASS | PASS | PASS | PASS | PASS | PASS | PASS | PASS | PASS | PASS | PASS | 2022-04-10
3 | Power-On | PASS | PASS | PASS | PASS | PASS | PASS | PASS | PASS | PASS | PASS | PASS | PASS | PASS | PASS | PASS | PASS | PASS | PASS | PASS | PASS | 2022-04-10
4 | Programming & Funtional Check | PASS | PASS | PASS | PASS | PASS | PASS | PASS | PASS | PASS | PASS | PASS | PASS | PASS | PASS | PASS | PASS | PASS | PASS | PASS | PASS | 2022-04-10
 | 121GW DMM used

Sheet: Visual Inspection
 | Pass/Fail
Visual Inspection Checks | SN001 | SN002 | SN003 | SN004 | SN005 | SN006 | SN007 | SN008 | SN009 | SN010 | SN011 | SN012 | SN013 | SN014 | SN015 | SN016 | SN017 | SN018 | SN019 | SN020
All components are populated, no cold solder joints OR bridges. | PASS | PASS | PASS | PASS | PASS | PASS | PASS | PASS | PASS | PASS | PASS | PASS | PASS | PASS | PASS | PASS | PASS | PASS | PASS | PASS
U1, U2 & U3 are populated in the right orientation | PASS | PASS | PASS | PASS | PASS | PASS | PASS | PASS | PASS | PASS | PASS | PASS | PASS | PASS | PASS | PASS | PASS | PASS | PASS | PASS

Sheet: Open-Shorts
 |  |  |  | Board fully discharged
Power-to-Power Resistance Measurements
 |  |  |  |  |  |  |  | Measured Value (Ω)
Net 1 | Pos DMM TP | Net 2 | Neg DMM TP | Notes | Acceptable Lower Limit (Ω) | Acceptable Upper Limit (Ω) | Expected Value | SN001 | SN002 | SN003 | SN004 | SN005 | SN006 | SN007 | SN008 | SN009 | SN010 | SN011 | SN012 | SN013 | SN014 | SN015 | SN016 | SN017 | SN018 | SN019 | SN020
BAT_RAW | BAT1.1 | +BATT | TP1 | Q7 body diode (full on)? | 6Meg | 9Meg | 7.7Meg | PASS | PASS | PASS | PASS | PASS | PASS | PASS | PASS | PASS | PASS | PASS | PASS | PASS | PASS | PASS | PASS | PASS | PASS | PASS | PASS
Power-to-Ground Opens
 |  |  |  |  |  |  |  | Measured Value (Ω)
Net 1 | Pos DMM TP | Net 2 | Neg DMM TP | Notes | Acceptable Lower Limit (Ω) | Acceptable Upper Limit (Ω) | Expected Value | SN001 | SN002 | SN003 | SN004 | SN005 | SN006 | SN007 | SN008 | SN009 | SN010 | SN011 | SN012 | SN013 | SN014 | SN015 | SN016 | SN017 | SN018 | SN019 | SN020
+BATT | TP1 | GND | TP2 | Mostly through the multivibrator circuit base resistors/BJTs? | 200K | 500k | 260K | PASS | PASS | PASS | PASS | PASS | PASS | PASS | PASS | PASS | PASS | PASS | PASS | PASS | PASS | PASS | PASS | PASS | PASS | PASS | PASS
Diode Checks
 |  |  |  |  |  |  |  | Measured Value (V)
Net 1 | Pos DMM TP | Net 2 | Neg DMM TP | Notes | Acceptable Lower Limit (V) | Acceptable Upper Limit (V) | Expected Value | SN001 | SN002 | SN003 | SN004 | SN005 | SN006 | SN007 | SN008 | SN009 | SN010 | SN011 | SN012 | SN013 | SN014 | SN015 | SN016 | SN017 | SN018 | SN019 | SN020
BAT_RAW | BAT1.1 | +BATT | TP1 | Q7 body diode (full on)? | 0.2 | 0.6 | 0.4 | PASS | PASS | PASS | PASS | PASS | PASS | PASS | PASS | PASS | PASS | PASS | PASS | PASS | PASS | PASS | PASS | PASS | PASS | PASS | PASS

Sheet: Power-On Checks
Power-On Checks
Note: Grounds from TP2
Current
 |  |  |  | Measured Value (mA)
Power Rail | Location | Notes / Conditions | Expected Value | SN001 | SN002 | SN003 | SN004 | SN005 | SN006 | SN007 | SN008 | SN009 | SN010 | SN011 | SN012 | SN013 | SN014 | SN015 | SN016 | SN017 | SN018 | SN019 | SN020
+BATT | TP1 | Unprogrammed board, multivbrator going normally, +3V in at room temp | 4mA to 8mA | PASS | PASS | PASS | PASS | PASS | PASS | PASS | PASS | PASS | PASS | PASS | PASS | PASS | PASS | PASS | PASS | PASS | PASS | PASS | PASS
Voltage
Note: Measure all points referenced to ground with the negative lead of DMM at TP1.
Voltage Rail | Pos DMM TP | Notes / Conditions | Expected Results | Measured Value (V)
 |  |  |  | SN001 | SN002 | SN003 | SN004 | SN005 | SN006 | SN007 | SN008 | SN009 | SN010 | SN011 | SN012 | SN013 | SN014 | SN015 | SN016 | SN017 | SN018 | SN019 | SN020

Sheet: PGRM & Functional Checks
Note: Board powered by normal CR2032 coin cell at about 3V, room temp normal atmel debugger | Pass/Fail
Pgrm & Functional Check | SN001 | SN002 | SN003 | SN004 | SN005 | SN006 | SN007 | SN008 | SN009 | SN010 | SN011 | SN012 | SN013 | SN014 | SN015 | SN016 | SN017 | SN018 | SN019 | SN020
Board multivibrator LED blinker blinks back and forth and responds to light levels vs blink frequency/duty | PASS | PASS | PASS | PASS | PASS | PASS | PASS | PASS | PASS | PASS | PASS | PASS | PASS | PASS | PASS | PASS | PASS | PASS | PASS | PASS
Board programs just fine with demo code. | PASS | PASS | PASS | PASS | PASS | PASS | PASS | PASS | PASS | PASS | PASS | PASS | PASS | PASS | PASS | PASS | PASS | PASS | PASS | PASS
RGB LED, white LED and green LED compass ring light up just fine. | PASS | PASS | PASS | PASS | PASS | PASS | PASS | PASS | PASS | PASS | PASS | PASS | PASS | PASS | PASS | PASS | PASS | PASS | PASS | PASS
NFC chip is detected by microcontroller (RGB LED goes green on boot up) and magnetometer chip is detected by micro (RGB LED goes blue on boot up). | PASS | PASS | PASS | PASS | PASS | PASS | PASS | PASS | PASS | PASS | PASS | PASS | PASS | PASS | PASS | PASS | PASS | PASS | PASS | PASS
LED ring compass and magentometer responds to Earth's magnetic field and points north | PASS | PASS | PASS | PASS | PASS | PASS | PASS | PASS | PASS | PASS | PASS | PASS | PASS | PASS | PASS | PASS | PASS | PASS | PASS | PASS
NFC chip is detectable by phone NFC reader. | PASS | PASS | PASS | PASS | PASS | PASS | PASS | PASS | PASS | PASS | PASS | PASS | PASS | PASS | PASS | PASS | PASS | PASS | PASS | PASS
Pushbutton press is recognized by micro. | PASS | PASS | PASS | PASS | PASS | PASS | PASS | PASS | PASS | PASS | PASS | PASS | PASS | PASS | PASS | PASS | PASS | PASS | PASS | PASS

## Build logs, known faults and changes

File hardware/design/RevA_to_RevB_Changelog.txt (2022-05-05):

2020/2021 Rev A to 2022 RevB

1. Change C4 & C5 to 22uF - DONE

2. DNP R1 and R2 (maybe) or replace with 1M to 10M	- DONE

3. Change R16 & R17 to 7.5kΩ	- DONE

4. Note that the battery is pos side up in silkscreen - DONE

5. Add hot glue spots to battery holder, extend battery holder negative pad out from under the holder. - SKIP, SUPERGLUE

6. Add a P-Fet Reverse Battery Protection	- DONE NXV75UPR

7. Add FWA art to the boack of the badge - DONE

8. Add more PCB art to the front of the badge ( https://youtu.be/Sbkvza8cKQE?t=1911 ) perhaps readjust mask to get more crystal blue, adust the silkscreen top to a bare  gold / ENIG instead for more of an atlantis TLE crystal necklace? ( https://i.pinimg.com/originals/f5/70/2b/f5702b80a7aa236c95a6224403604152.jpg ) - DONE

9. Widen the top hole into a ellipsoid slot instead for a wider lanyard clamps - DONE

10. Delete C2 to make room for the P-Fet reverse bat protection - DONE

11. Bump up "+BATT" silkscreen on J4 to be +2.5V to +3.5V - DONE

12. Add fiducials on the top side of the board IMPORTANT - SKIP USE PANEL RAILS FOR FIDUCIALS

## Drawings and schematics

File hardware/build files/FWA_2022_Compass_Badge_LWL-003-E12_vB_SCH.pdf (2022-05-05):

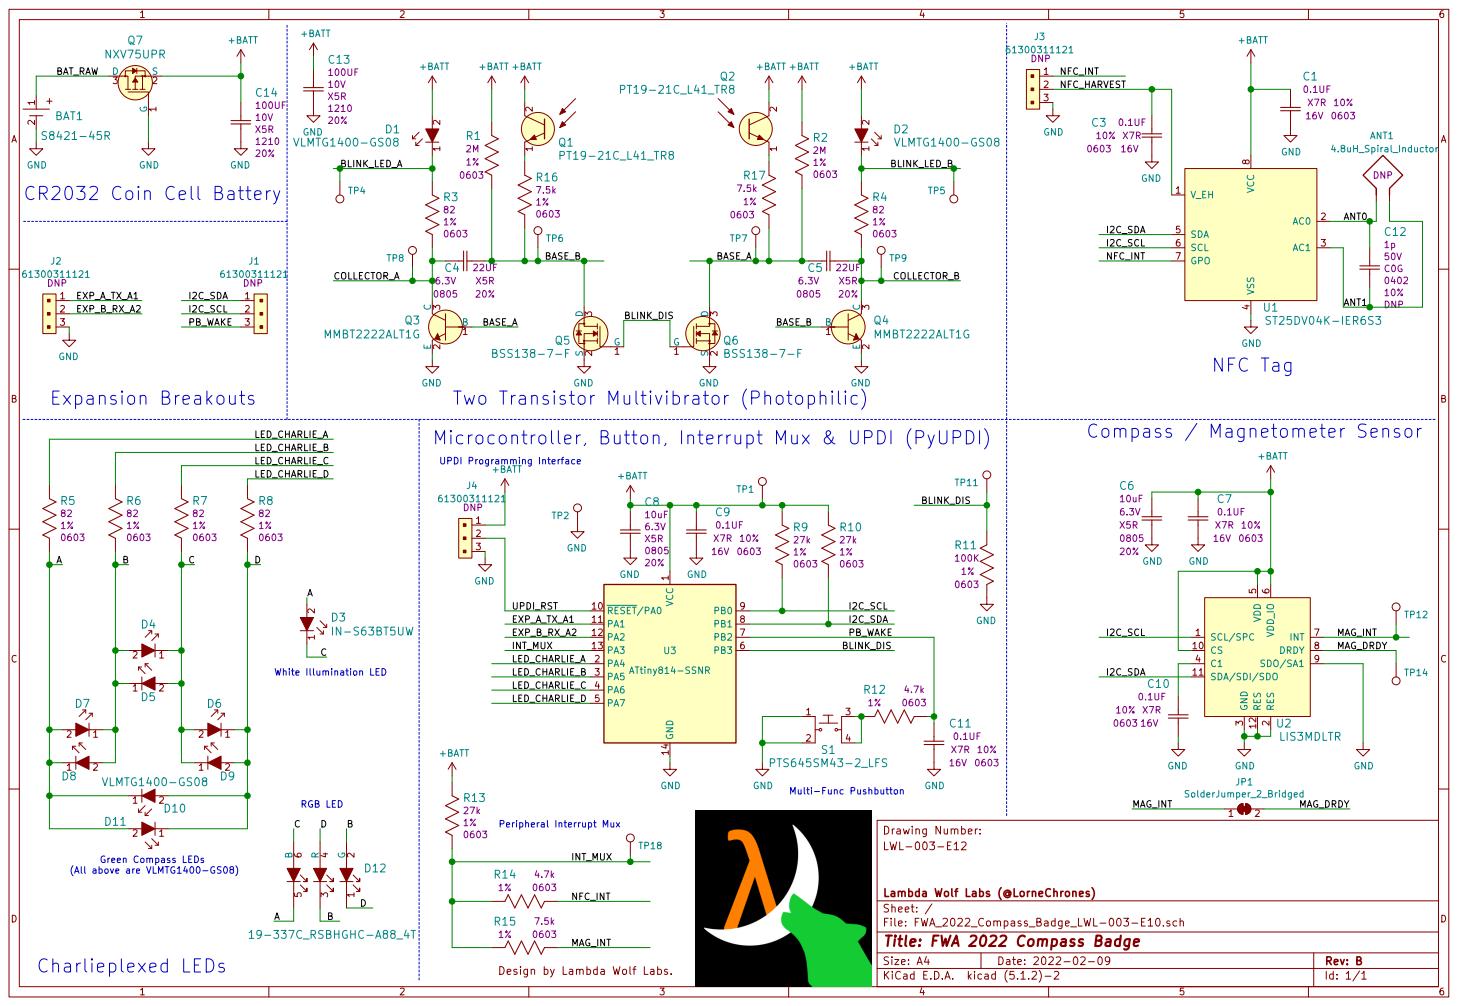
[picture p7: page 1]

4 SDA 5 SCL 6 GPO 7 VCC

Two Transistor Multivibrator (Photophilic)
Microcontroller, Button, Interrupt Mux & UPDI (PyUPDI) R9
+BATT GND R13
61300311121 DNP

File: FWA_2022_Compass_Badge_LWL-003-E10.sch Sheet: / Lambda Wolf Labs (@LorneChrones) LWL-003-E12 Drawing Number:

Id: 1/1 Title: FWA 2022 Compass Badge

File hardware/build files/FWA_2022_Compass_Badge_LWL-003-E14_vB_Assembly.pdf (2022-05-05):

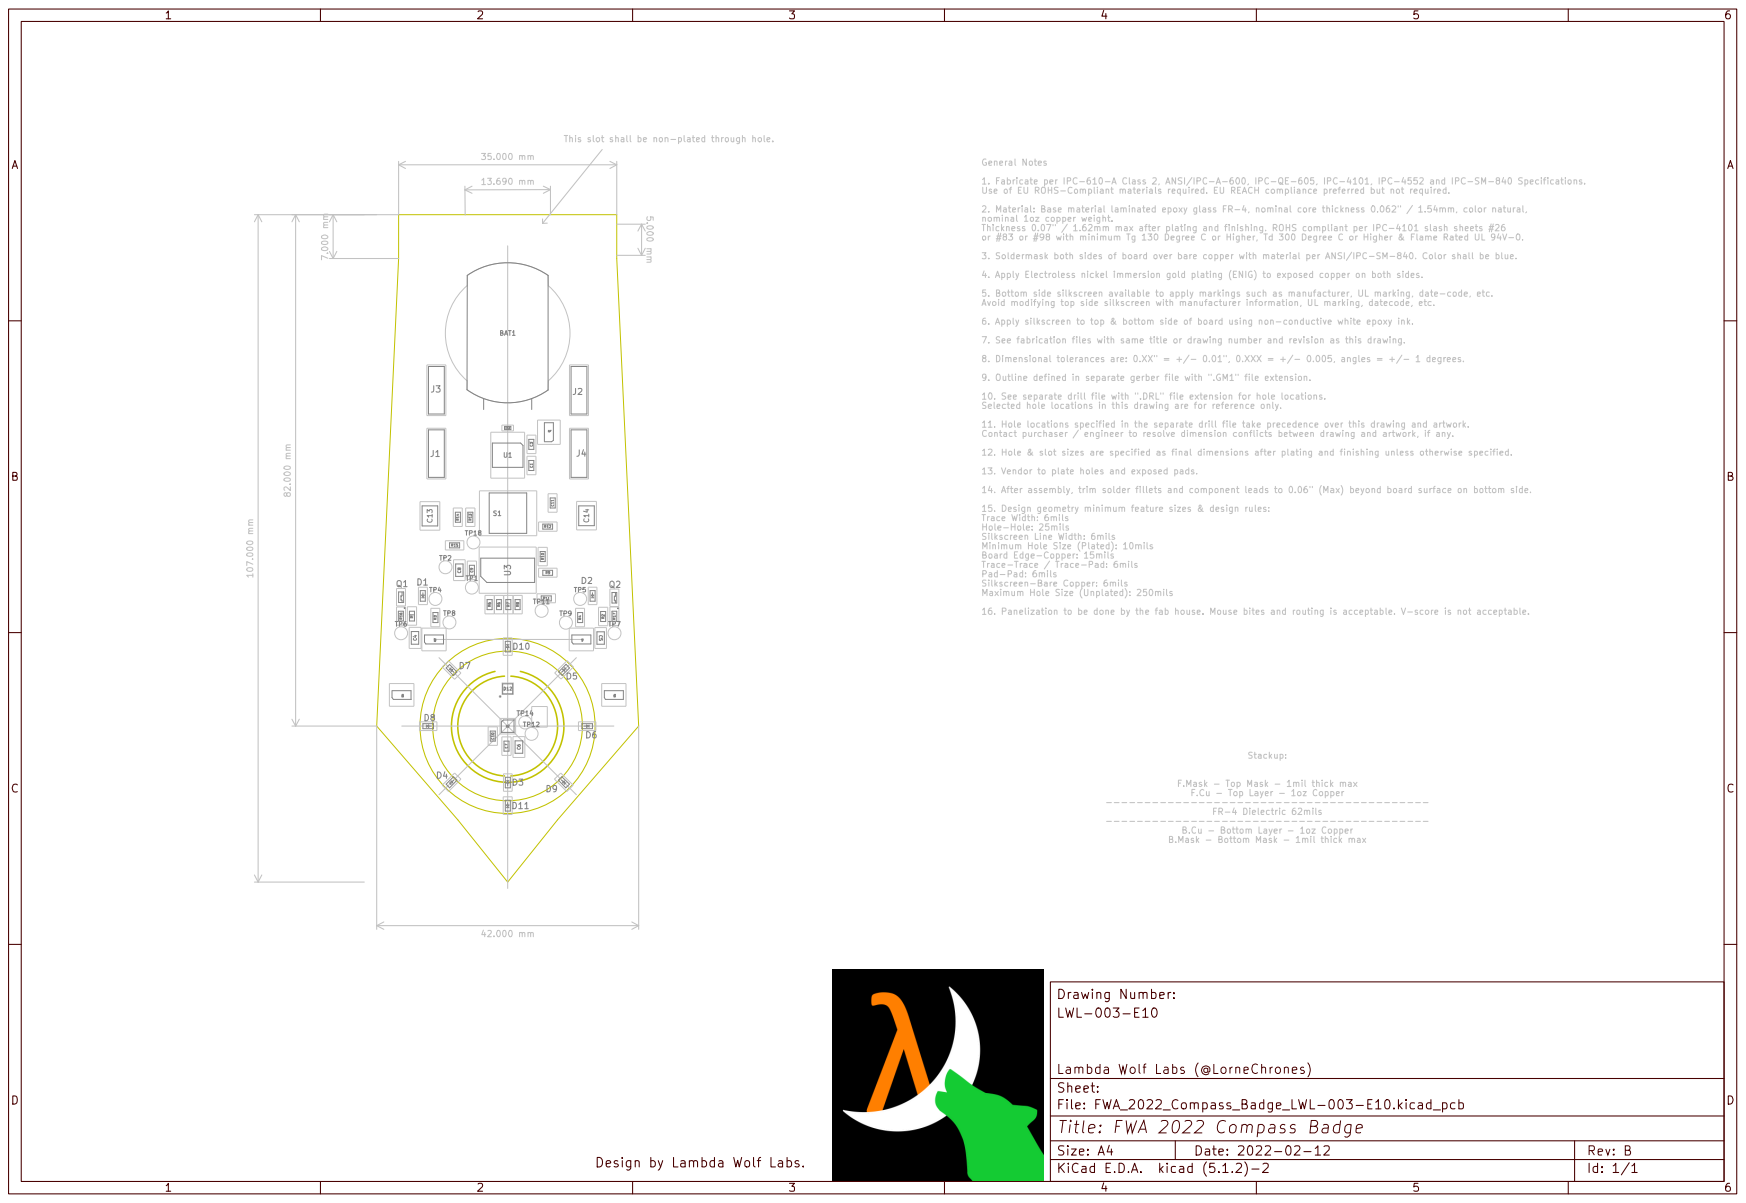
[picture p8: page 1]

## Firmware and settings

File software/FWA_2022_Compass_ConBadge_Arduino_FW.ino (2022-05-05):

/*
 * FWA_2022_Compass_ConBadge_Arduino_FW.ino
 *
 * Created: 4-15-2022 thru 5-4-2022
 * Author : @LorneChrones / Nick / Lambda Wolf Labs
 * Repo: https://github.com/lambdawolflabs
 * Project/FW Number: FWA 2022 Compass ConBadge
 * Revision: Release
 *
 * MCU Used: ATTINY814
 * MCU Datasheet: http://www.microchip.com/mymicrochip/filehandler.aspx?ddocname=en599388
 * MCU Errata: http://ww1.microchip.com/downloads/en/DeviceDoc/ATtiny214-414-814-Errata-and-Clarification-DS40002115C.pdf
 *
 * MCU Notes: Might recommend upgrading to a ATTINY1614 in the future for more FLASH space (but chip shortage *pain* ;_;)
 *
 * Programming: https://github.com/microchip-pic-avr-tools/pymcuprog
 * (Or Arduino IDE built in //SerialUPDI or ATMEL-ICE tool)
 *
 * Arduino Core Used (Installation instructions provided too) here: https://github.com/SpenceKonde/megaTinyCore
 * megaTinyCore Arduino Recommended Settings To Use For the FWA 2022 Compass ConBadge (Bootloader burn required for some):
 *    Board:                            ATTINY814         (No optiboot)
 *    Chip:                             ATTINY814
 *    Clock:                            4MHz Internal           
 *    millis()/micros() Timer:          Enabled (Default Timer)
 *    Startup Time:                     8ms
 *    BOD Voltage Level:                2.1V  (Unofficial)
 *    BOD Mode when Active/Sleeping:    Enabled/Enabled
 *    Save EEPROM:                      EEPROM Retained
 *    attachInterrupt() Version:        On all pins, like usual
 *    printf():                         Default (doesn't print floats)
 *    Wire Library Mode:                Master or Slave
 *    
 * Additional Fuse Notes:
 *    Default APPEND, Default BOOTEND, CRC disabled, RESET pin function is UPDI. Disable Timer D pin output.
 *    Due to a silicon bug, NEVER SET OSCCFG.OSCLOCK TO '1' (Errata 2.2.2).
 *    Leave device unlocked, fuse & lock bits can be editted.
 * 
 * Compass Notes: I've provided these compasses as largely uncalibrated so they aren't guaranteed to point North by default.
 *                However I've "rough calibrated" them somewhat and left in additional links to how you can properly calibrate them yourself.
 *    
 *    
 * Boot Up:
 *    1.LED Multivibrator blinkers startup up enabled at power on. (D1 and D2)
 *    2.MCU (U3) cycles the White LED (D3) and then the R, G and then B LEDs (in the RGB package, D12). 
 *    3.MCU turns off the RGB LED.
 *    4.MCU I2C scans for the ST25DV NFC chip (U1), if it detects it, it turns briefly sets the RGB LED to Green, if not it briefly sets the RGB LED to Red. 
 *        4a.If the MCU found the NFC chip then it'll read its contents and load any user configuration settings into memory for later use. (See "NFC User Configuration Commands" section for command set, syntax and usage)
 *    5.MCU I2C scans for the LIS3MDL Compass chip (U2), if it detects it, it turns briefly sets the RGB LED to Blue, if not it briefly sets the RGB LED to Red. 
 *    6.MCU sequence turns on the compass ring LEDs (D10, D5, D6, D9, D11, D4, D8 and D7 in that order) clockwise. 
 *    7.MCU turns of all of the compass ring LEDs, the RGB LED and white LED and enters Mode 0.
 *
 * Modes:
 *    Swap between modes by holding the pushbutton for longer than one second. Short button presses (<1 second)toggles/runs the Action for that particular mode.
 *    When a new mode is entered, a corresponding LED on the LED compass ring is blinked 3 times. Starting clockwise at the top LED (D10 is Mode 0, D5 is Mode 1, D6 is Mode 2, etc).
 *    
 *    
 *    Mode 0: Multivibrator enabled, everything else off.    - Short Press: Toggles Multivibrator On/Off.
 *    Mode 1: RGB LED: Solid Blue, everything else off.    - Short Press: Toggles RGB LED from Solid Blue to Solid Green to Solid Red  then back to Solid Blue.
 *    Mode 2: White LED: Solid White, everything else off.    - Short Press: Toggles White LED from Solid White to 1Hz Blink to SOS Morse Pattern then back to Solid White.
 *    Mode 3: Green LED Ring Demo: Binary Count, Fast Spinner (CW/CCW), Persistence Of Vision Full Ring. - Short Press: Cycles between Green LED Ring Fast Spinner clockwise, Green LED Fast Spinner counterclockwise, Persistence Of Vision Solid Green Ring & Persistence Of Vision Binary Count.
 *    Mode 4: Compass Demo/Green LED ring points north according to U2. - Short Press: N/A
 *    Mode 5: Custom Profile Defined By NFC EEPROM (User can enable whatever LEDs or LED patterns to whatever values simultaneously in this mode, see "NFC User Configuration Commands" section for supported commands/settings).   - Short Press: Reread/rescan NFC EEPROM memory for user configuration.
 *    Mode 6: Rainbow Random Mode, randomly jumps around between different LEDs being enabled/disabled at a 3 sec interval.   - Short Press: N/A
 *    Mode 7: Everything Off (Including Multivibrator), MCU goes into sleep mode.             - Short Press: Wake up and go to next mode
 *    
 *     
 * NFC User Configuration Commands:
 *    Use only "text mode" NFC entries when writing to the NFC chip to program it. Its safe to still mix in other entries like socials, URLs, etc in the NFC.
 *	  Text Mode Entry Programming Format (without quotations): "led=X!"
 *    Where X can be "0" thru "7", "r" or "R", "g" or "G", "b" or "B", "w" or "W", "p" or "P" and "n" or "N"
 *    "0" thru "7" simply solid light up one of the LEDs on the Green LED ring (clockwise)
 *    "r" or "R", "g" or "G", "b" or "B" simply solidly light up either the Red, Green or Blue LED in the RGB LED chip.
 *    "w" or "W" simply solidly lights up the White LED.
 *    "p" or "P" does a progress bar animation with the green LED ring.
 *    "n" or "N" does a Night Rider/KITT (or Cylon) eye animation with the green LED ring.
 *   
 *
 * Lorne: Feel free to use this code and modify, redistribute, etc with it. I'm not a coder by training (EE by trade), so there's plenty of improvments here.
 *
 * Lorne: Thank you for attending the panel and I hope you enjoyed it / learned something new too! ^_^
 * 
 * GPL v3 License
 *
 * 1. Permission is hereby granted, free of charge, to any person obtaining a copy
 * of this software and associated documentation files (the "Software"), to deal
 * in the Software without restriction, including without limitation the rights
 * to use, copy, modify, merge, publish, distribute, sublicense, and/or sell
 * copies of the Software, and to permit persons to whom the Software is
 * furnished to do so, subject to the following conditions:
 *
 * 2. The above copyright notice and this permission notice shall be included in all
 * copies or substantial portions of the Software.
 *
 * 3. THE SOFTWARE IS PROVIDED "AS IS", WITHOUT WARRANTY OF ANY KIND, EXPRESS OR
 * IMPLIED, INCLUDING BUT NOT LIMITED TO THE WARRANTIES OF MERCHANTABILITY,
 * FITNESS FOR A PARTICULAR PURPOSE AND NONINFRINGEMENT. IN NO EVENT SHALL THE
 * AUTHORS OR COPYRIGHT HOLDERS BE LIABLE FOR ANY CLAIM, DAMAGES OR OTHER
 * LIABILITY, WHETHER IN AN ACTION OF CONTRACT, TORT OR OTHERWISE, ARISING FROM,
 * OUT OF OR IN CONNECTION WITH THE SOFTWARE OR THE USE OR OTHER DEALINGS IN THE
 * SOFTWARE.
 *
 * 4. This software is strictly NOT intended for safety-critical or life-critical applications.
 * If the user intends to use this software or parts thereof for such purpose additional
 * certification is required.
 *
 */ 

//Includes & Defines
#include <Wire.h>
#include <Math.h>
#include <avr/sleep.h>


//Math predefines
#define twoPI    6.283185307
#define rad2deg   57.29577951
#define rad90deg  1.570796327
#define rad270deg 4.71238898



//Pin Definitions
#define EXP_A_TXD_A1  8   //PIN1_bm //PA1, Output
#define EXP_B_RXD_A2  9   //PIN2_bm //PA2, Input
#define INT_MUX       10  //PIN3_bm //PA3, Input/ADC
#define LED_CHARLIE_A 0   //PIN4_bm //PA4, Output
#define LED_CHARLIE_B 1   //PIN5_bm //PA5, Output
#define LED_CHARLIE_C 2   //PIN6_bm //PA6, Output
#define LED_CHARLIE_D 3   //PIN7_bm //PA7, Output

#define I2C_SCL       7   //PIN0_bm //PB0, Output/I2C SCL
#define I2C_SDA       6   //PIN1_bm //PB1, Bidir/I2C SDA
#define PB_WAKE       5   //PIN2_bm //PB2, Input
#define BLINK_DIS     4   //PIN3_bm //PB3, Output


//Additional LED defines for later use
#define White    8
#define RGBBlue   9
#define RGBGreen  10
#define RGBRed    11


//NFC User Defined Programs
#define ProgressBar 12
#define NightRider	13
#define Idle		255


//I2C Device Definitions
#define ST25DV_eeprom_addr    0x53
#define ST25DV_registers_addr 0x57
#define LIS3MDL_addr          0x1C


//LIS3MDL Register names & addresses
#define LIS3MDL_WHO_AM_I  	0x0F
#define LIS3MDL_CTRL_REG1   0x20
#define LIS3MDL_CTRL_REG2   0x21
#define LIS3MDL_CTRL_REG3   0x22
#define LIS3MDL_CTRL_REG4   0x23
#define LIS3MDL_CTRL_REG5   0x24
#define LIS3MDL_STATUS_REG  0x27
#define LIS3MDL_OUT_X_L     0x28
#define LIS3MDL_OUT_X_H     0x29
#define LIS3MDL_OUT_Y_L     0x2A
#define LIS3MDL_OUT_Y_H     0x2B
#define LIS3MDL_OUT_Z_L     0x2C
#define LIS3MDL_OUT_Z_H     0x2D
#define LIS3MDL_TEMP_OUT_L  0x2E
#define LIS3MDL_TEMP_OUT_H  0x2F
#define LIS3MDL_INT_CFG     0x30
#define LIS3MDL_INT_SRC     0x31
#define LIS3MDL_INT_THS_L   0x32
#define LIS3MDL_INT_THS_H   0x33



//Globals
//(Relatively) Simple compass calibration:
//https://www.bot-thoughts.com/2011/04/quick-and-dirty-compass-calibration-in.html
int16_t mag_x = 0;
  int16_t mag_x_offset = -1020;   //You'll need to rerun manual calibration to find the offsets (which are the averages of the min and max values collected);
int16_t mag_y = 0;
  int16_t mag_y_offset = -525;
int16_t mag_z = 0;
  int16_t mag_z_offset = 1137;
uint8_t mag_buff = 0;

double mag_x_double = 0.0;
  double mag_x_scale = -7.608;
double mag_y_double = 0.0;
  double mag_y_scale = 7.097;
//double mag_z_double = 0.0;
  //double mag_z_scale = 1;
double angle_double = 0.0;

int8_t angle = 0;

//Advanced compass calibration:
//https://github.com/YuriMat/MagMaster
//float calibrated_values[3];  //Xcal, Ycal, Zcal
//float uncal_values[3];       //""
//float mag_x_cal;
//float mag_y_cal;
//float mag_z_cal;

char buff = 0;

char button_held = 0;



//Sytem Wide Globals & Mode state variables.
volatile char current_mode = 255;             //For debugging purposes, do not set the current_mode to match next_mode on startup. Set next_mode here to zero to enter mode zero on boot.
volatile char next_mode = 0;
volatile char userNFCProgrammedAction = 0;
volatile char shortPressDetected = false;

volatile unsigned long millisTimestamp = 0;

volatile unsigned long millisBinaryCount = 0;
volatile unsigned long millisModeFive = 0;

int randSeedFromNFC = 1111;

volatile char modeOneStorage = 0;
volatile char modeTwoStorage = 0;
	volatile char modeTwoStepCounter = 0;
	volatile char modeTwoSOSCounter = 0;		
volatile char modeThreeStorage = 0;
	volatile char modeThreeSpinnerPos = 0;
	volatile char modeThreeBinaryCount = 0;
	volatile char modeThreePOVSpeed = 75;
volatile char modeFiveStorage = 0;
	volatile char modeFiveProgressBar = 0;
	volatile char modeFiveNightRider = 0;
	


//Charlieplex LED Definitions, in order of clockwise direction green LEDs, then the white LED and lastly the RGB LEDs.
//  DCBA
//0bxxxx
//                  D to A,C to B , C to D,D to C , A to D,B to C , B to A,A to B , A to C,C to A , B to D,D to B
//                  D10   ,D5   , D6    ,D9     , D11   ,D4     , D8    ,D7     , D3    ,D12B   , D12G  ,D12R
const unsigned char charlieDIR[] = {0b1001,0b0110 , 0b1100,0b1100 , 0b1001,0b0110 , 0b0011,0b0011 , 0b0101,0b0101 , 0b1010,0b1010};
const unsigned char charlieOUT[] = {0b1000,0b0100 , 0b0100,0b1000 , 0b0001,0b0010 , 0b0010,0b0001 , 0b0001,0b0100 , 0b0010,0b1000};





//Func Defines

//Charlieplexe routine to drive the LEDs output
void charlieplex(unsigned char LEDNumber, unsigned char Enabled) {
  if (Enabled == 0) {
    VPORTA.OUT &= 0x0F;
    _NOP();
    _NOP();
    VPORTA.DIR &= 0x0F;
    _NOP();
    _NOP();
  } else {
    VPORTA.OUT &= 0x0F;
    _NOP();
    _NOP();
    VPORTA.DIR &= 0x0F;
    _NOP();
    _NOP();
    
    VPORTA.DIR |= ((charlieDIR[LEDNumber]) << 4);
    _NOP();
    _NOP();
    VPORTA.OUT |= ((charlieOUT[LEDNumber]) << 4);
    _NOP();
    _NOP();
  }
}



//Boot Up Routine
void BootUp() {

  //Setup CPU clocks.
  CCP = 0xD8;
  CLKCTRL.MCLKCTRLA = 0x00; //Run CLK_CPU at 4MHz from the internal 16MHz RC Osc, factory temp/accuracy compensation values automatically loaded
  CCP = 0xD8;
  CLKCTRL.MCLKCTRLB = 0x03;
  
  
  //CLKCTRL.MCLKLOCK = 0x00;  //Leave the MCLKCTRLA, MCLKCTRLB, OSC20MCALIBA and OSC20MCALIBB registers available to modify during runtime.
  CCP = 0xD8;
  CLKCTRL.OSC20MCTRLA = 0x02; //Force ably start the 16MHz RC Oscillator in all modes even when not requested (incl. standby)
  CCP = 0xD8;
  CLKCTRL.OSC32KCTRLA = 0x02; //Force ably start the 32kHz ULP Oscillator in all modes even when not requested (incl. standby)
  CCP = 0xD8;
  CLKCTRL.XOSC32KCTRLA = 0x00;//Disable the 32.768kHz Ext XTAL circuitry entirely.
  
  while((CLKCTRL.MCLKSTATUS & 0x11) == 0x01) {  //Wait until OSC20MS is stable and SOSC/CLK_MAIN is no longer clock switching.
    _NOP();
  }

  
  //Setup BOD & VLM, most of this is setup in fuses and can be ignored.
  CCP = 0xD8;
  BOD.CTRLA = 0x15;     //125Hz sample, BOD ENABLED @ 125Hz in both Active & Sleep
  BOD.CTRLB = 0x01;     //BODLEVEL1 2.15V, W.C. brownout at 2.032V which is still above the 1.9V minimum board wide op voltage.
  BOD.VLMCTRLA = 0x00;    //VLM Thres 5% above BOD, thus 2.25V VLM trigger, this is still above the EOL voltage of CR2032s at 2V.
  BOD.INTCTRL = 0x00;     //Disable interrupts for now, will comeback later after setup...
   
  
  //Setup GPIO
  charlieplex(0,0);         //Disable Charlieplex
  PORTA.PIN4CTRL = 0x04;    //Disable input buffers and disable pullups on all the charlieplex pins since they'll only be used for outputs.
  PORTA.PIN5CTRL = 0x04;
  PORTA.PIN6CTRL = 0x04;
  PORTA.PIN7CTRL = 0x04;
  
  PORTA.PIN3CTRL = 0x04;    //Temporarily disable the input buffer to INT_MUX. It'll become enabled along with interrupts when the I2C devices are setup.


  //Set BLINK_DIS as an output pin and ensure it starts LOW to enable the LED BJT multivibrator.
  pinMode(BLINK_DIS, OUTPUT);
  digitalWrite(BLINK_DIS, LOW);


  
  //Set the was-alternate, now-primary UART output to an OUTPUT pin prior to //Serial.begin
  //pinMode(EXP_A_TXD_A1, OUTPUT);


  //Serial.begin(9600);

  //Setup PORTMUX for the alternate pins on the UART for the expansion pins, TWI/I2C pins on standard pinout, EVOUT not used, SPI not used.
  PORTMUX.CTRLA = 0x00;
  PORTMUX.CTRLB = 0x01;   //Specifically for UART alt pins on PA1/PA2
  PORTMUX.CTRLC = 0x00;

  //Serial.println(" ");


  //Serial.print("[ "); //Serial.print(millis()); //Serial.print(" ] ");
  //Serial.print("FWA 2022 Compass Badge startup. ");
  //Serial.println("All clocks, pins, BOD previously setup.");
  

  delay(1000);

  //Serial.print("[ "); //Serial.print(millis()); //Serial.print(" ] ");
  //Serial.println("RGB + White exercise");
  charlieplex(White,1);
  delay(500);
  charlieplex(RGBRed,1);
  delay(500);
  charlieplex(RGBGreen,1); 
  delay(500);
  charlieplex(RGBBlue,1);
  delay(500);

  charlieplex(0,0);
  delay(500);


  Wire.begin();

  //Serial.print("[ "); //Serial.print(millis()); //Serial.print(" ] ");
  //Serial.print("Scanning for ST25DV NFC chip...");
  //Check to see if the ST25DV is there by pinging out and reading the UID byte 6 register (fixed to 0x02)
  //If detected then flash the RGB to green, otherwise flash red.
  Wire.beginTransmission(ST25DV_registers_addr); 
  Wire.write(0x00);
  Wire.write(0x1E);
  Wire.endTransmission(false);

  Wire.requestFrom(ST25DV_registers_addr, 1);
  while (Wire.available()) {
    buff = Wire.read();   
  }

  if(buff == 0x02) {
    charlieplex(RGBGreen,1);
    //Serial.println("FOUND!");

	LoadUserNFCConfigurations();
  } else {
    charlieplex(RGBRed,1);
    //Serial.println("NOT FOUND!");    
  }

  delay(500);
  
  charlieplex(0,0);
  
  delay(500);

  //Serial.print("[ "); //Serial.print(millis()); //Serial.print(" ] ");
  //Serial.print("Scanning for LIS3MDL Compass chip...");
  //Check to see if the LIS3MDL is there by reading the WHO_AM_I register (fixed to 0x3D);
  //If detected then flash the RGB to blue, otherwise flash red.
  Wire.beginTransmission(LIS3MDL_addr);   //Access the ST25DVxx User Memory, write
  Wire.write(LIS3MDL_WHO_AM_I);
  Wire.endTransmission(true);

  Wire.requestFrom(LIS3MDL_addr, 1);
  while (Wire.available()) {
    buff = Wire.read();   
  }

  if(buff == 0x3D) {
    charlieplex(RGBBlue,1);
    //Serial.println("FOUND!");
  } else {
    charlieplex(RGBRed,1);
    //Serial.println("NOT FOUND!");
  }
  
  delay(500);
  
  charlieplex(0,0);
  
  delay(500);

  //Serial.print("[ "); //Serial.print(millis()); //Serial.print(" ] ");
  //Serial.println("LED Compass Ring Exercise");
  for(char x = 0 ; x < 8 ; x++) {
    charlieplex(x,1);
  
    delay(100);
  }

  charlieplex(0,0);

  //Enable PB_WAKE internal pull-up. 50kOhm worst case internall pull-up and 100nF 5xRC debounce circuit ->   25mSec to wait for a full charge minimum
  pinMode(PB_WAKE, INPUT_PULLUP);
  delay(25);

  digitalWrite(BLINK_DIS, LOW);
}



//Setup the LIS3MDL compass sensor for later use
void LIS3MDL_Setup() {
  //Serial.print("[ "); //Serial.print(millis()); //Serial.print(" ] ");
  //Serial.println("Setting up LIS3MDL compass sensor settings.");
  //LIS3MDL temp sensor enabled, medium performance on X/Y axes, 10Hz ODR, no FAST_ODR, self-test disabled
  Wire.beginTransmission(0x1C);
  Wire.write(LIS3MDL_CTRL_REG1);
  Wire.write(0xB0);       
  Wire.endTransmission(true);

  //LIS3MDL 16 gauss full scale
  Wire.beginTransmission(0x1C);
  Wire.write(LIS3MDL_CTRL_REG2);
  Wire.write(0x60);       
  Wire.endTransmission(true);

  //LIS3MDL low power mode disabled, single conversion mode
  Wire.beginTransmission(0x1C);
  Wire.write(LIS3MDL_CTRL_REG3);
  Wire.write(0x01);       
  Wire.endTransmission(true);
  
  //LIS3MDL medium performance mode on Z axis
  Wire.beginTransmission(0x1C);
  Wire.write(LIS3MDL_CTRL_REG4);
  Wire.write(0x04);       
  Wire.endTransmission(true);
  

  //LIS3MDL no FAST_READ, do not block data updates
  Wire.beginTransmission(0x1C);
  Wire.write(LIS3MDL_CTRL_REG5);
  Wire.write(0x00);       
  Wire.endTransmission(true);
  

  //LIS3MDL disable interrupts
  Wire.beginTransmission(0x1C);
  Wire.write(LIS3MDL_INT_CFG);
  Wire.write(0x08);       
  Wire.endTransmission(true);
}
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
void loop() {
	pinMode(PB_WAKE, INPUT_PULLUP);
	pushbuttonHandler();

	ModeChange();
	
	
	//Different operating modes
	switch(current_mode) {
		case 0:
			ModeZero();
			break;
			
		case 1:
			ModeOne();
			break;
			
		case 2:
			ModeTwo();
			break;
			
		case 3:
			ModeThree();
			break;
		
		case 4:
			ModeFour();
			break;
		
		case 5:
			ModeFive();
			break;
		
		case 6:
			ModeSix();
			break;
			
		
		case 7:
			digitalWrite(BLINK_DIS, HIGH);
			set_sleep_mode(SLEEP_MODE_PWR_DOWN);
			attachInterrupt(PB_WAKE, WakeUp, LOW);
			charlieplex(White,0);
			sleep_enable();
			sleep_cpu();
			sleep_disable();
			pinMode(PB_WAKE, INPUT_PULLUP);
			delay(5);
			while(digitalRead(PB_WAKE) == LOW) {
				while(digitalRead(PB_WAKE) == LOW) {
					delay(1);
				}
				delay(5);
			}
			delay(25);
			digitalWrite(BLINK_DIS, LOW);
			next_mode = 0;
			break;
		
		default:
			break;
	}


}
